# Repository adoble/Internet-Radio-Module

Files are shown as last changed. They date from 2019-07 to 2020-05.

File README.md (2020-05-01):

# Modular Audio Project - Internet Radio Module

An internet radio source that (eventually) should  communicate with the other modules (such as the amplifier) using I2S (or something similar).

The current version does not output I2S, but instead a normal stereo audio signal.

## System Diagram

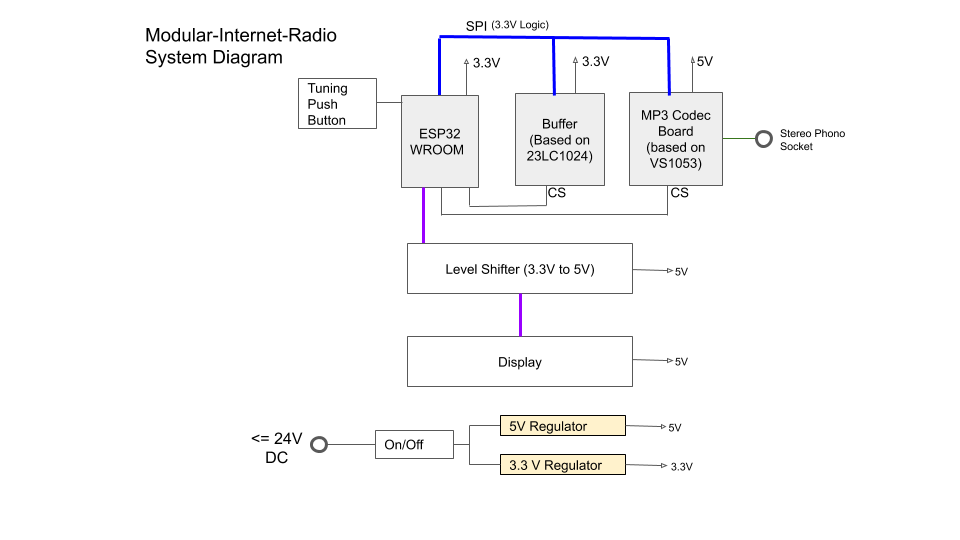
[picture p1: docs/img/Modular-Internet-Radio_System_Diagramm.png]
System Diagram


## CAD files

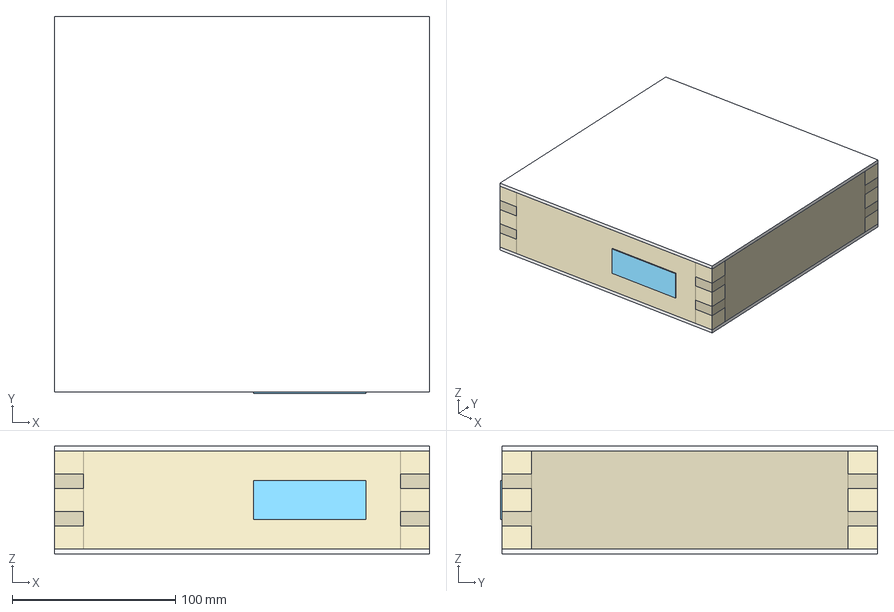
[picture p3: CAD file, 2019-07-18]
hardware/enclosure/IR_ENCLOSURE.FCStd
230.0 x 231.0 x 66.0 mm
Top
Bottom
Screen_Asymb
Right_Panel
Left_Panel
Back_Panel

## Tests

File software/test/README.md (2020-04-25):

# Test Routines

This directory contains a set of sketches used to test the internet radio module
as it was being constructed.

* [BlinkTest](./BlinkTest) - Oscillates a signal on selected pins.
* [ESP_spiram](./ESP_spiram) - This is a basic example showing how to use ESP8266Spiram library
* [HelloWorld](./LCDHelloWorldLCD)  - Demonstrates the use a 16x2 LCD display.
* [SPITestSimple](./SPITestSimple) - Simple test of the SPI RAM using the standard SPI library
* [SPIRamTest](./SPIRamTest) - Simple test of the SPI RAM using a user  determined SPI "port" (own creation of SPIClass)
* [SpiRAMRingBufferTest](./SpiRAMRingBufferTest) - Comprehensive set of tests of the ring buffer Library
* [WebClient](./WebClient) - Test of the custom reading of HTTP data.

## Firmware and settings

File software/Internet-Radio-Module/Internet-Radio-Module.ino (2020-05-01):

/**
* Internet Radio
*
*  This sketch:
*    - connects (WPA encryption)to an internet radio site using an ESP32 module
*    - reads the mp3 data stream
*    - buffers the data in an external SPI controlled RAM
*    - transfers it to the VS1053 so that it can decode
*      the mp3 data into an audio signal.
*
*
* Standard Libraries
* ==================
* Arduino           - Standard Arduino library
* SPI               - Serial Progamming Interface standard library
* WiFi              - Standard Arduino  WiFi library
* ESP8266_Spiram    - Used by SPIRingBuffer as a driver for the 23LC1024.
*                     Handles basic communication with the memory chip.
* LiquidCrytal      - Controls the LCD display.
*
* Created Libaries (for the project)
* ==================================
* SPIRingBuffer     - A ring buffer that is implemented to use an SPI based
*                     23LC1024 RAM. This is used to buffer the data to that
*                     sporadic gaps in the internet connection are
*                     "smoothed out".
* Lemon_VS1053      - A local library to control the VS1053
*
*/

#include <Arduino.h>

#include <WiFi.h>
#include <LiquidCrystal.h>

#include <SPI.h>
#include <EEPROM.h>
#include "Lemon_VS1053.h"
#include "SPIRingBuffer.h"
#include "PushButtonClicks.h"
#include "Groups.h"
#include "credentials.h"

const char programName[] = "Internet-Radio-Module 30.04.2020";

const char stationFile[] = "http://www.andrew-doble.homepage.t-online.de/ir/stations.txt";

const int VOLUME = 10; // Volume for both channels. Lower is louder.


// Pin setup for the VS1053
const int DREQ = 26;
const int XCS  = 25;
//const int XRST = 35;  // 35 is input only on wroom
const int XRST = 33;  //NOTE: The reset jumper on the
                      // Adafruit Feather MusicMaker w/Amp needs to be broken

const int XDCS = 27;

// Pin setup for the 23LC1024 RAM
const int RAMCS = 22;     // Chip select for the external RAM used for the ring buffer

// Setup the VS1053 Lemom player using standard hardware SPI pins
Lemon_VS1053 player = Lemon_VS1053(XRST, XCS, XDCS, DREQ);

// Set up the external RAM as a ring buffer
SPIRingBuffer ringBuffer(RAMCS);

// Initialize the LCD library by associating any needed LCD interface pins
// with the microcontroller pin number it is connected to
const int rs = 12, en = 2, d4 = 16, d5 = 4, d6 = 5, d7 = 21;
LiquidCrystal lcd(rs, en, d4, d5, d6, d7);
long blinkTime = 0;
long currentTime = 0;
boolean blankDisplay = true;

// The control push button used to change the stations
PushButton controlButton;
const int controlButtonPin = 14;

// Button states
const int NOTHING      = 0; //Nothing or Bounce
const int HOLD        =  1; // Pressed and not released for a long time
const int LONG_PRESS  =  2; // Pressed and released after a long time
const int CLICK        = 3; // A single click
const int DOUBLE_CLICK = 4;
const int TRIPLE_CLICK = 5;
const int FOUR_CLICKS  = 6;
const int FIVE_CLICKS  = 7;

// The station selection states
enum SelectionState {STATION_SELECT, GROUP_SELECT} selectionState;

// Line 0 of the LCD display is used as either the status display
// or to display the name of the currently selected group.
// To handle this correctly, keep a track of what is being displayed.
enum StatusDisplayState  {NONE, GROUP, CONNECT};
StatusDisplayState statusDisplayState = NONE;

// The display bufer used for scolling text ticker tape style
const int DISPLAY_BUFFER_LEN = 16; // Number of characters the LCD can display
const int SPACING = 2;             // Number characters used to seperate strings
                                   // in a ticker tape style diplay
const int ROLL_DISPLAY_TIME = 350; // How quickly the display is rolled in ms
int scrollTime;
char displayBuffer[DISPLAY_BUFFER_LEN + 1];
int tickerTapeStep = 0;

// Flag to ensure that the ring buffer is fully loaded on startup
bool bufferInitialized = false;

// The threshold at which the buffer will be faster loaded.
const int THRESHOLD = ringBuffer.RING_BUFFER_LENGTH / 5;   // 20%

// The skip flag to allow the buffer to catch up
int skip = 0;

// Has the station currently being listened to bee saved in the EEPROM.
boolean stationSaved = false;

// When was the station first listened to. This is used
// to only store the station in the EEPROM after it has been
// listered to for a period of time.
unsigned long startListeningTime;

// The number of milliseconds that a station is listened to
// before it is saved in the EEPROM.
const long LISTEN_TIME_BEFORE_SAVE = 10000;

// Setup the WIFI objects
//WiFiMulti WiFiMulti;  //TODO remove

// HTTP connection codes
const int HTTP_CODE_OK = 200;
const int HTTP_CONNECTION_TIMED_OUT = -1;
const int HTTP_CONNECTION_FAILED = -2;



// WiFi configuration using the defines in credentials.h
const char* ssid     = WIFI_SSID;
const char* password = WIFI_PWD;

// Dimensions of the station group data structure
const int maxNumberStationsInGroup = 20;
const int maxNumberGroups = 20;

const int PAYLOADLEN = 4000;
char payload[PAYLOADLEN];

// The structure containing the groups and the stations
Groups* groups;
Group* currentGroup;
Station* currentStation;

struct URL {
  String protocol = "";
  String host = "";
  String port = "";
  String path = "";
};

// The EEPROM holds the last station that was selected as type bytes,
// the group number and the station number within that group
const uint8_t EEPROM_SIZE = 3;
const uint8_t EEPROM_ID = 0x99;  // Used to identify valid data
const uint8_t EEPROM_ID_ADDR = 0;
const uint8_t EEPROM_GROUP_ADDR = 1;
const uint8_t EEPROM_STATION_ADDR = 2;

// Create a buffer  to read in the mp3 data. Thsi is set to DATABUFFERLEN as this
// is the amount that can be transfered to the VS1053 in one SPI operation.
const int DATABUFFERLEN = 32;
uint8_t mp3Buffer[DATABUFFERLEN];
int bufferIndex = 0;

// Number of bytes available in the read stream
size_t nBytes;

// Client to read the mp3 data from the internet station.
WiFiClient client;

// Default setting for the tone control
int toneControl = 0;

// Inhibits the loop from further processing if there was
// a failure with the setup
boolean setupFailure = false;

// A set of (normally fatal) errors that cannot be recovered from.
const int ERROR_CURRENT_STATION_NULL = -100;
const int ERROR_CURRENT_GROUP_NULL = -101;
const int ERROR_GROUP_NULL = -102;

// Function prototypes
void handleRedirect();
void handleOtherCode(int);
void setStation();
void initializeGroupStructure();
void readStationConfiguration();
void clearDisplayLine(int);
void tickerTape(int, char*, int, char*, int, int);
int  httpConnect(const char[]);
int  httpConnect(const char[], boolean);
void parseURL(const char[], URL*);
void printStationStucture();
void displayConnecting();
void printLCD(String, String);
void displayCurrentGroup();
void rollStationDisplay();
void printParsedURL(URL*);
void changeStation();
void changeStation(int, int);

void setup() {

  Serial.begin(115200);
  delay(10);

  // So we know what version we are running
  Serial.println(programName);
  Serial.println();

  // Set up the control button to change te stations
  pinMode(controlButtonPin, INPUT_PULLUP);

  // set up the LCD with the  number of columns and rows
  lcd.begin(16, 2);

  // Before initialising using the libraries make sure that the CS pins are
  // in the right state
  pinMode(XCS, OUTPUT);
  digitalWrite(XCS, HIGH);
  pinMode(XDCS, OUTPUT);
  digitalWrite(XDCS, HIGH);
  pinMode(RAMCS, OUTPUT);
  digitalWrite(RAMCS, HIGH);
  delay(1);

  // Initialise the ring buffer
  ringBuffer.begin();
  Serial.println("Ring buffer initialised.");

  // Initialize the player
  if ( !player.begin()) { // initialise the player
   Serial.println("Error in MP3 codec initialisation!");
     player.dumpRegs();
  } else {
     Serial.println("MP3 codec initialised.");
  }

  if (player.readyForData()) {
    Serial.println("Ready for data");
  } else {
    Serial.println("Not ready for data");
  }

  // Make sure the VS1053 is in MP3 mode.
  // For some boards this is not the case.
  while (!player.readyForData()) {}
  player.setMP3Mode();

  // Set the volume
  while (!player.readyForData()) {}
  player.setVolume(VOLUME,VOLUME);  

  // Connect to the WIFI access point
  Serial.println("Attempting to connect to WIFI AP");
  displayConnecting();
  lcd.setCursor(0,1);
  lcd.print( "WiFi");


  // Wait for WiFi connection.
  const int MAX_CONNECTION_ATTEMPTS = 20;
  int nAttempts = 0;

  WiFi.begin(ssid, password);

  while((WiFi.status() != WL_CONNECTED && nAttempts <  MAX_CONNECTION_ATTEMPTS)) {
    Serial.print("WiFi Connection attempt "); Serial.println(nAttempts + 1);
    delay(500);
    nAttempts++;
  }

  Serial.println();
  if (nAttempts >= MAX_CONNECTION_ATTEMPTS) {
     Serial.print("FAILED to connect to WIFI AP after ");
     Serial.print(MAX_CONNECTION_ATTEMPTS);
     Serial.println(" attempts!");
     printLCD("FAILED to", "connect to WiFi");
     setupFailure = true;
  } else {
     Serial.println("Connected to WIFI AP");
     printLCD("Connected to", "WiFi");
  }

  // Set the initial station
  initializeGroupStructure();

  if((WiFi.status() == WL_CONNECTED)) {
     lcd.clear();
     lcd.print("Connected to WIFI");
     readStationConfiguration();

     // Read the EEPROM to find the last station set
     int lastGroup = 0;
     int lastStation = 0;
     if (EEPROM.begin(EEPROM_SIZE)) {
       // Has the EEPROM been initialised?
       uint8_t id = EEPROM.read(EEPROM_ID_ADDR);
       if (id == EEPROM_ID) {
         // Read the last values and select the cuurent station
         lastGroup = EEPROM.read(EEPROM_GROUP_ADDR);
         lastStation = EEPROM.read(EEPROM_STATION_ADDR);
         changeStation(lastGroup, lastStation);
       } else {
         // Initialise the EEPROM with the first station in the first group
         EEPROM.write(EEPROM_ID_ADDR, EEPROM_ID);
         EEPROM.write(EEPROM_GROUP_ADDR, 0);
         EEPROM.write(EEPROM_STATION_ADDR, 0);
         EEPROM.commit();
         // By default the first group and station have been selected
       }
     }

     setStation();
  }

  // Set all timing variables to now
  scrollTime = currentTime = blinkTime = startListeningTime = millis();
}

void loop() {
  int nRead = 0;
  int maxBytesToRead;

  // If there has been a failure in the setup then
  // just return
  if (setupFailure) return;

  // See if we have to change the station
  switch(controlButton.buttonCheck(millis(), digitalRead(controlButtonPin))) {
    case HOLD : // Toggle the selection state between group selection and stations selection;
             // Blick the group name and clear the station (second) line.
             if (selectionState == STATION_SELECT) selectionState = GROUP_SELECT;
             else {
               selectionState = STATION_SELECT;
               displayCurrentGroup();
               displayCurrentStation();
               // Reinitialise the  buffer
               bufferInitialized = false;
               ringBuffer.begin();
               setStation();
             }
             break;
    case CLICK :
              if (selectionState == GROUP_SELECT) {
                changeGroup();
                displayCurrentGroup();
                displayCurrentStation();
              } else {  // Station select
                // Reinitialise the buffer
                bufferInitialized = false;
                ringBuffer.begin();
                // Now change the station and connect to it
                changeStation();
                setStation();
                displayCurrentStation();
              }
             break;
    default: break; // Ignore other button selectionStates
   }

   // Determine how the groups of station is displayed when it can be changed
   if (selectionState == GROUP_SELECT) {
    blinkGroup();
    // Stop music being played whilst the group is being selected
    return;
   }

   // Now check if the station length is longer than 16, i.e, the number of
   // characters that fit on a line in the LCD. If not then roll the
   // station name in the display ticker tape style.
   if (strlen(currentStation->getName()) > 16 && selectionState != GROUP_SELECT) {
     rollStationDisplay();
   }

  if (!bufferInitialized) {
    // Load up the buffer
    nBytes = client.available();
    if (nBytes) {
      // Read in chunks of up to 32 bytes

      //    availableSpace()       nBytes         ->    maxBytesToRead
      //    =================   =================     ===============
      //      >=DATABUFFERLEN   >DATABUFFERLEN         DATABUFFERLEN
      //      >=DATABUFFERLEN   <=DATABUFFERLEN        nBytes
      //      <DATABUFFERLEN          -               availableSpace

      if (ringBuffer.availableSpace() < DATABUFFERLEN) maxBytesToRead = ringBuffer.availableSpace();
      else maxBytesToRead = (nBytes> DATABUFFERLEN ? DATABUFFERLEN : nBytes);
      nRead = client.readBytes(mp3Buffer, maxBytesToRead);
      // Transfer to buffer
      for (int i = 0; i < nRead; i++) {
        ringBuffer.put(mp3Buffer[i]);
      }
      if (ringBuffer.availableSpace() == 0)  {
          bufferInitialized = true;
          Serial.println("Buffer initialised");
          startListeningTime = millis();
          stationSaved = false;
      }
    }

  }   // -- if bufferInitialized

  if (bufferInitialized && (statusDisplayState != GROUP)) {
    displayCurrentGroup();
  }



  if (bufferInitialized && !stationSaved && (millis() - startListeningTime) > LISTEN_TIME_BEFORE_SAVE) {
    // Listened to the station for LISTEN_TIME_BEFORE_SAVE ms so save the station in the EEPROM.
    // In this was the last station listened to will be played when
    // powered up again.
    saveCurrentStation();
    stationSaved = true;
  }


  // Adding data to ring buffer
  // is ring buffer full?
  //    no:   is source data available?
  //            yes: read source, data --> ring buffer
  //            no:  no-op
  //    yes: no-op
  //
  if (bufferInitialized) {
    if (ringBuffer.availableSpace() > DATABUFFERLEN) {
      nBytes = client.available();
      if (nBytes) {
        // read up to 32 bytes
        nRead = client.readBytes(mp3Buffer, (nBytes> DATABUFFERLEN ? DATABUFFERLEN : nBytes));
        // Transfer to buffer
        for (int i = 0; i < nRead; i++) {
          ringBuffer.put(mp3Buffer[i]);
        }
      }
    }
  }


  // Skip a transfer to the VS1053 to give the buffer a chance to reload if
  // has the data amout has fallen below THRESHOLD
  skip = ((bufferInitialized && (ringBuffer.availableData() < THRESHOLD)) ? (skip++)%2 : 0);

  // Moving data to VS1053
  // does VS1053 accept data? and not skip?
  //    yes: does ring buffer have data?
  //           yes: ring buffer data --> VS1053
  //           no:  no-op
  //    no:  no-op
  if (bufferInitialized  && !skip) {
      // Transfer to VS1053
      if (player.readyForData()) {
        nRead = (ringBuffer.availableData() > DATABUFFERLEN ? DATABUFFERLEN : ringBuffer.availableData());
        for (int i= 0; i < nRead; i++) {
          mp3Buffer[i] = ringBuffer.get();
        }
        player.playData(mp3Buffer, nRead);
      }

  }

}

/*
 * Initialise the structure used to hold the stations and group data.
 */
void initializeGroupStructure() {
   groups = new Groups(maxNumberStationsInGroup, maxNumberGroups);
}

/*
 *  Read the station and group data from a file stored at a fixed URL on the
 *  Internet. In this way, the stations and groups can always be changed
 *  without having to reprogramm the firmware.
 */
void readStationConfiguration() {
  int fatalError = 0;

  Serial.print("HTTP begin to read stations...\n");
  lcd.clear();
  lcd.write("Reading stations");

  int httpCode = httpConnect(stationFile);

  // httpCode will be negative on error
  if (httpCode <= 0) {
    Serial.printf("Unable to read stations: HTTP GET... failed, error: %d\n", httpCode);
    return;
  }

  // HTTP header has been sent and server response header has been handled
  Serial.printf("[HTTP] GET stations... code: %d\n", httpCode);  //TODO get rid of printf fucntions

  // file found at server
  if (httpCode == HTTP_CODE_OK) {
    int index = 0;
    int c;
    boolean payloadFull = false;
    while ( (c = client.read()) != -1) {
      if (index < PAYLOADLEN - 1) {
        payload[index++] = c;
      } else {
        payloadFull = true;
        break;
      }
    }

  if (!payloadFull) {
      //Terminate the payload string
      payload[index] = '\0';
  } else {
    // Move backwards until the last CR and terminate the
    // sttring after this. In this way station definition
    // files that are too large for the payload buffer are
    // simply ignored (altough a console message is given)
    Serial.println("Station defintion file is too large for buffer and has been truncated.");

    while (payload[index] != '\r') {
      index--;
    }
    // Terminatethe string after the CR
    payload[index +1] = '\0';
  }

  int payloadLength = index;

  // Setup the groups structure
  groups->setup(payload, payloadLength);

  // Print out the group and station structure to the console
  printStationStucture();

  // Set the LCD to the first group and station
  if (groups != NULL) {
    groups->begin();
    currentGroup = groups->next();
    if (currentGroup != NULL) {
      lcd.clear();
      lcd.print(currentGroup->getName());
      currentGroup->begin();
      currentStation = currentGroup->next();
      if (currentStation != NULL)  {
        lcd.setCursor(0,1);
        lcd.print(currentStation->getName());
      } else {
        fatalError = ERROR_CURRENT_STATION_NULL;
      }
    } else {
      fatalError = ERROR_CURRENT_GROUP_NULL;
    }
  } else {
  fatalError = ERROR_GROUP_NULL;
  }

  if (fatalError) {
    Serial.printf("FATAL ERROR in setting up group/stations [%i]", fatalError );
    lcd.clear();
    lcd.print("ERROR: Get Help!");
  }

  client.stop();

  }
} // -- readStationConfiguration

/*
 * Display the selected group in top line of the  LCD display
 */
void displayCurrentGroup() {
  clearDisplayLine(0);
  if (currentGroup != NULL) {
    lcd.setCursor(0,0);
    lcd.print(currentGroup->getName());
  }
  statusDisplayState = GROUP;
  displayCurrentStation();
}

/*
 * Display the selected station in the bottom line of the LCD display
 */
void displayCurrentStation() {
  if (currentStation == NULL) {
    currentGroup->begin();
    currentStation = currentGroup->next();
  }
  if (currentStation != NULL) {
    clearDisplayLine(1);
    lcd.setCursor(0,1);
    lcd.print(currentStation->getName());
  }
}

/*
 *  Show the user in the top line of the LCD display that the radio is attempting to
 *  connect to the selected station.
 */
void displayConnecting() {
  clearDisplayLine(0);
  lcd.setCursor(0,0);
  lcd.print("Connecting to");
  statusDisplayState = CONNECT;
}

/*
 * Based on the ordinal indexs of group and station set the current group
 * and the current station.
 * If the specified ordinal index for the group is incorrect then
 * set the current group to the first group.
 * If the specified ordinal index for the station in that group is incorrect
 * then set to the first station in that group.
 */
void changeStation(int groupIndex, int stationIndex) {
    groups->begin();
    if (groupIndex < groups->numberGroups()) {
    for (int i = 0; i <= groupIndex; i++) {
      currentGroup = groups->next();
    }
  } else {
    // Invalid group index so set group to the first one
    currentGroup = groups->next();
  }

  currentGroup->begin();
  if (stationIndex < currentGroup->numberStations() ) {
    for (int i = 0; i <= stationIndex; i++) {
      currentStation = currentGroup->next();
    }
  } else {
    // Something is wrong so set to the first station in the group
    currentStation = currentGroup->next();
  }

 // Reset any ticker tape state
  tickerTapeStep = 0;

}

/*
 * Change to the next station in the current group. If no more stations
 * then loop back to the first station in the group.
 */
void changeStation() {
  currentStation = currentGroup->next();
  if (currentStation == NULL) {
    currentGroup->begin();
    currentStation = currentGroup->next();
  }
  if (currentGroup == NULL) Serial.println("PANIC GROUP");
  if (currentStation == NULL) Serial.println("PANIC STATION");

  // Reset any ticker tape state
  tickerTapeStep = 0;
}

/*
 * Change to the next group. If no more groups then loop back to the
 * first group.
 */
void changeGroup() {
  currentGroup = groups->next();
  if (currentGroup == NULL) {  // Cycle through the groups
   groups->begin();
   currentGroup = groups->next();
  }

  // Set the first station in the group
  currentGroup->begin();
  currentStation = currentGroup->next();
}

/*
 * Roll the station name ticker type style. In this way long stations names
 * are fully displayed.
 */
void rollStationDisplay() {
   if ((millis() - scrollTime) > ROLL_DISPLAY_TIME) {  // Time to roll the display,
     tickerTape(tickerTapeStep, currentStation->getName(), strlen(currentStation->getName()), displayBuffer, DISPLAY_BUFFER_LEN, SPACING);
     lcd.setCursor(0,1);
     lcd.print(displayBuffer);
     tickerTapeStep++;
     if (tickerTapeStep == (DISPLAY_BUFFER_LEN + SPACING - 1)) tickerTapeStep = 0;
     scrollTime = millis();
  }
}

/*
 * Blink the name of the group. This is used to show the user that the radio
 * is in group selection mode.
 */
void blinkGroup() {
  lcd.setCursor(0,1);
  lcd.print("                "); // Clear the station details
  currentTime = millis();
  if (currentTime > blinkTime) {
    // Set the blink time to the future
    blinkTime = currentTime + 500;
    if (blankDisplay) {
      lcd.setCursor(0,0);
      lcd.print("                ");
      blankDisplay = false;
    } else {
      lcd.setCursor(0,0);
      if (currentGroup == NULL) Serial.println("PANIC HERE");
      lcd.print(currentGroup->getName());
      blankDisplay = true;
    }
  }
}
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

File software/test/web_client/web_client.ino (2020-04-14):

/*
 *  This sketch requests data over HTTP from a radio station
 *
 */

#include <WiFi.h>

#include "credentials.h"

const char* ssid     = WIFI_SSID;
const char* password = WIFI_PWD;

//const char* host = "streams.rpr1.de";
//const char* requestURI = "/rpr-kaiserslautern-128-mp3";

//const char * stationURL = "http://streams.rpr1.de/rpr-kaiserslautern-128-mp3";
const char * stationURL = "http://bbcmedia.ic.llnwd.net/stream/bbcmedia_radio1_mf_p";
//String stationURL = "http://streams.rpr1.de/rpr-kaiserslautern-128-mp3";

struct URL {
  String protocol = "";
  String host = "";
  String port = "";
  String path = "";
};


uint8_t mp3Buffer[128];
int nRead = 0;

WiFiClient client;

// Function prototypes
int connectStation(String);
void parseURL(String, URL*);
void printURL(URL*);


void setup()
{
    Serial.begin(115200);
    delay(10);

    // We start by connecting to a WiFi network

    Serial.println();
    Serial.println();
    Serial.print("Connecting to ");
    Serial.println(ssid);

    WiFi.begin(ssid, password);

    while (WiFi.status() != WL_CONNECTED) {
        delay(500);
        Serial.print(".");
    }

    Serial.println("");
    Serial.println("WiFi connected");
    Serial.println("IP address: ");
    Serial.println(WiFi.localIP());

    int responseCode = connectStation(stationURL);

    Serial.print("HTTP Response Code: ");
    Serial.println(responseCode);


}

void loop()
{

    // Read all the bytes  of the reply from server
    if(client.available()) {
        nRead = client.readBytes(mp3Buffer, 128);
        Serial.println(nRead);
    }


}

/**
* Connect to the station specified by the urlString.
* Returns the HTTP response code
*/
int connectStation(String urlString) {
  URL url;

//TEST
//  parseURL("http://stations.com/streaming/music.mp3", &url);
//  printURL(&url);
//  parseURL("http://domain.stations.com/channels/pop/more_music", &url);
//  printURL(&url);
//  parseURL("http://domain.stations.com:80/x/more_music.mp3", &url);
//  printURL(&url);
//
//  return -1000;
//
  parseURL(urlString, &url);


  int httpPort;
  if (url.port.length() == 0) httpPort =  80;
  else httpPort = url.port.toInt();

  if (!client.connect(url.host.c_str(), httpPort)) {
      Serial.println("Connection failed");
      return -2;  //TODO Failed to connect
  }

  // We now create a URI for the request
  //String url = requestURI;


  Serial.print("Requesting URL: ");
  printURL(&url);

  // This will send the request to the server
  client.print(String("GET ") + url.path + " HTTP/1.1\r\n" +
               "Host: " + url.host + "\r\n" +
               "Connection: keep-alive\r\n\r\n");

  unsigned long timeout = millis();
  while (client.available() == 0) {
      if (millis() - timeout > 5000) {
          Serial.println("ERROR: Timeout!");
          client.stop();
          return -1;  //TODO timeout
      }
  }

  // Now read the response code.
  String protocol;
  String responseCode;
  String headerFields;

  char c;
  while (client.available() && (c = client.read()) != ' ') {
    protocol += c;
  }
  Serial.print(protocol);
  Serial.print(' ');


   while (client.available() && (c = client.read()) != ' ') {
    responseCode += c;
  }
  Serial.print(responseCode);
  Serial.print(' ');


  int endHeaderCount = 0 ;
  while (client.available()) {
    c = client.read();
    headerFields += c;

    if  (c == '\r' || c == '\n' ) endHeaderCount++;
    else endHeaderCount = 0;

    if (endHeaderCount == 4) {
      Serial.println(headerFields);
      break;
    }
  }

  return responseCode.toInt();
}

/*
 * Parses a string represeting a URL into a struct.
 * The mmebers of the struct can be used for standard
*  Internet connectivity libraries.
 */
void parseURL(String urlString, URL* url) {
  // Assume a valid URL

  enum URLParseState {PROTOCOL, SEPERATOR, HOST, PORT, PATH} state = PROTOCOL;

  url->protocol = "";
  url->host = "";
  url->port = "";
  url->path = "/";


  for (int i = 0; i < urlString.length(); i++) {
    switch(state)
    {
      case PROTOCOL: if (urlString[i] == ':') state = SEPERATOR;
                     else url->protocol += urlString[i];
                     break;
      case SEPERATOR: if (urlString[i] != '/') {
                          state = HOST;
                          url->host += urlString[i];
                      }
                      break;
      case HOST: if (urlString[i] == ':') state = PORT;
                 else {
                   if (urlString[i] == '/') state = PATH;
                   else url->host += urlString[i];
                   }
                 break;
      case PORT: if (urlString[i] == '/') state = PATH;
                 else  url->port += urlString[i];
                 break;
      case PATH: url->path += urlString[i];

    }
  }
}

/*
 * Prints out a formatted version of the URL. Only used for test purposes.
 */
void printURL(URL* url) {
  Serial.print(url->protocol);
  Serial.print("://");
  Serial.print(url->host);
  if (url->port.length() > 0) {
    Serial.print(":");
    Serial.print(url->port);
  }
  //Serial.print("/");
  Serial.println(url->path);
}

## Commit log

2019-02-26 Pause/Mute button added (can mute radio), Button library added, cleaned up
2019-02-28 Station change from a simple push button
2019-07-18 Extended structure
    [IR_ENCLOSURE.FCStd, internet-radio-module.kicad_pcb, internet-radio-module.sch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]
2019-07-19 Main wiring diagram
    [internet-radio-module.sch, pcb.sch]
2019-07-19 Contrast pot on PCB; Control button symbol changed
    [internet-radio-module.sch]
2019-07-21 Breadboard components added
    [internet-radio-module.sch, pcb.sch]
2019-07-21 Added SparkFun library for ESP32 Thing board
2019-07-27 Added level shifting buffers
    [internet-radio-module.sch, pcb.sch]
2019-07-27 Changed the pins for new circuit with VS1053
2019-08-11 Using ESP8266Spiram library to correctly drive the 24LC1024
    [Internet-Radio-Module.ino]
2019-09-06 Corrected errors in station changing
    [Stations.ino]
2019-10-06 Added test-rig project
    [pcb.sch, test-rig-2019-10-06-18-34-25.sch, test-rig.kicad_pcb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]
2019-10-12 Test rig
    [test-rig.sch]
2019-10-13 Added programming header
    [test-rig.sch]
2019-10-23 WROOM and MEM layout completed
    [test-rig.kicad_pcb, test-rig.sch]
2019-10-23 Removed double 10u decoupling caps in VS1053 power supply
    [test-rig.sch]
2019-11-17 New schematic
    [BufferRAM.sch, Control.sch, MP3Codec.sch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]
2019-12-06 New borad layout - routing incomplete
    [Control.sch, MP3Codec.sch, Power.sch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]
2019-12-12 Routing completed
    [irm_pcb.kicad_pcb]
2019-12-13 Layout completed
    [irm_pcb.kicad_pcb]
2019-12-13 Board size reduced
    [irm_pcb.kicad_pcb]
2019-12-14 Rev 1
    [irm_pcb.kicad_pcb]
2019-12-14 Rev 1.1
    [irm_pcb.kicad_pcb]
2019-12-20 Added WROOM decoupling capacitors
    [WROOM_Processor.sch, irm_pcb.kicad_pcb]
2019-12-27 Added 3V3 copper flows
    [irm_pcb.kicad_pcb]
2020-01-04 Connecting message has correct behaviour
    [Internet-Radio-Module.ino]
2020-03-29 Control sw working and wiring updated
    [wiring.sch, wiring_loom.kicad_pcb, wiring_loom.sch]
2020-03-30 Radio, display and control button work
2020-04-22 Test sketch to oscillator a set of pins
    [BlinkTest.ino]
2020-04-22 Updated the external wiring
    [wiring_loom.sch]
2020-05-01 Increased volume for current amplifier
